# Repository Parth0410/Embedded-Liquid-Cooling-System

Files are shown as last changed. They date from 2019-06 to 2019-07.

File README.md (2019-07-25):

# Embedded-Liquid-Cooling-System
To maintain the Temperature of the water in the bottle.

About this Project:-

The Peltier Tile is the module which has two sides, one becomes cold and other heats up on applying the certain voltage. The main Objective of the project is to make a Liquid Cooler using a Peltier Tile. In this, the base is created which has the Microcontroller, Cooling Fan, and the Temperature sensors which continuously detects and display the temperature of the water as well as of the base in the display.  
As the temp. of water reaches the threshold level i.e., 15 ºC, the Fan and Peltier Tile stops working, and as the temp. again reaches above the threshold i.e., 25 ºC, both again starts working. This will help the battery to work for long duration and resulting the Water remains Cool.

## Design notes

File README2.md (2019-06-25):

Here for this project I designed my own PCB for microcontroller board as well as for the Boost circuit.
The purpose of designing my own PCB is to consider the size of PCB which should not be bigger than the base of the water bottle besause the development board are too big for this.

So, the details like block diagram, all data sheets required, circuit diagram, component list with values and their component code and the other required things are attached in this.

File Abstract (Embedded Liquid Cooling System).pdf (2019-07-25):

# Liquid Cooling Using Peltier Tile

## Abstract:

Our project is based on the Thermoelectric Effect. The Thermoelectric Effect is the direct conversion of temperature differences to electric voltage and vice versa via a thermocouple. A thermoelectric device creates voltage when there is a different temperature on each side. Conversely, when a voltage is applied to it, heat is transferred from one side to the other, creating a temperature difference. The term "Thermoelectric Effect" encompasses three separately identified effects which are: Seebeck Effect, Peltier Effect and Thomson Effect. The detailed description of all these effects you can see by clicking here. (https://en.wikipedia.org/wiki/Thermoelectric_effect)

So, for this project we are using a Peltier Module which works on the principle of Peltier Effect. The Peltier effect is the presence of heating or cooling at an electrified junction of two different conductors when a current is made to flow through a junction between two conductors, A and B, heat may be generated or removed at the junction.

For our project, we designed our own AVR Controller Board in Eagle CAD and it has the minimal peripherals we need because we have size and shape constraints.

The main Objective of the project is to make a Liquid Cooler using a Peltier Tile. In this, the base is created which has the Microcontroller board (Self-designed), Cooling Fan, and the Temperature sensors which continuously detects and display the temperature of the water in the LCD.

As the temp. of water reaches the threshold level i.e., 15 ºC, the Fan and Peltier Tile stops working, and as the temp. again reaches above the threshold i.e., 25 ºC, both again starts working. This will help the battery to work for long duration and resulting the Water remains Cool.

Project Members: | Project Guide:
1. Parth Rastogi (190250330050) | 1. Mr. Ninad
2. Piyush Sharma (190250330052) | C-DAC Hyderabad

### 3. Paras Srivastava (190250330049) 4. Pawar Nikesh Shivajirao (190250330051)

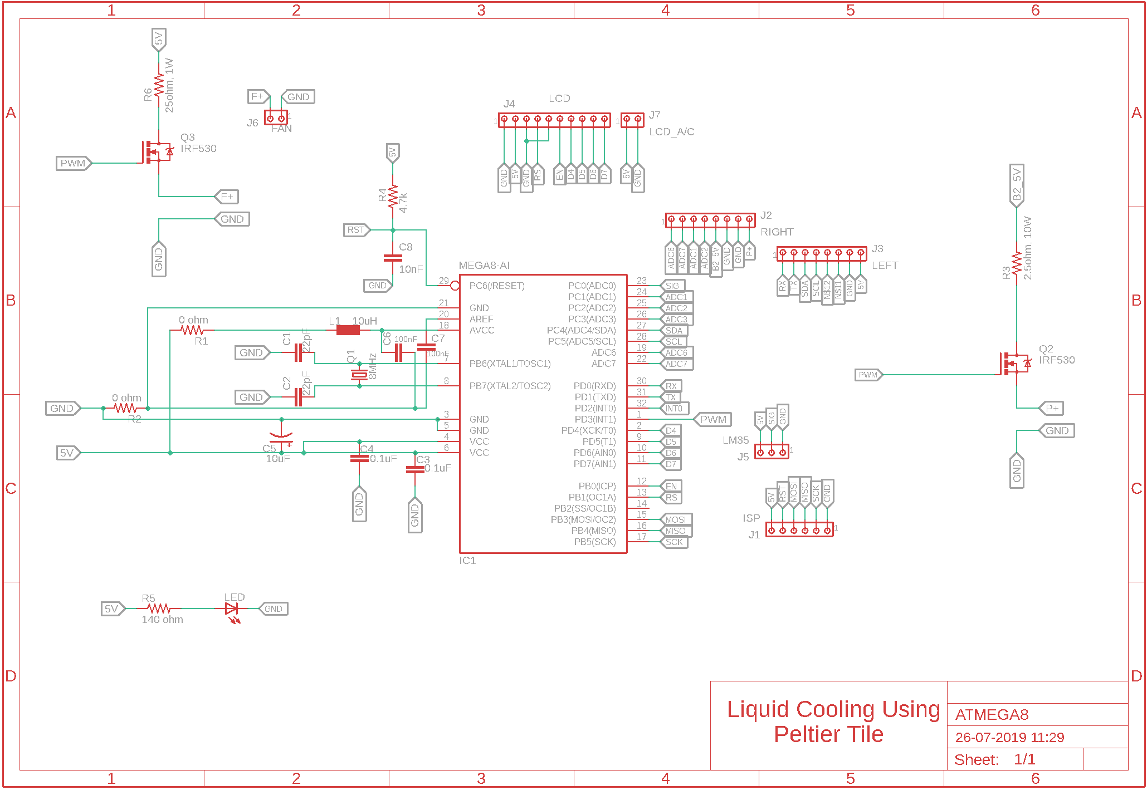
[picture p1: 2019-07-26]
Eagle Schematics Images/Final uC Board Schematic.png

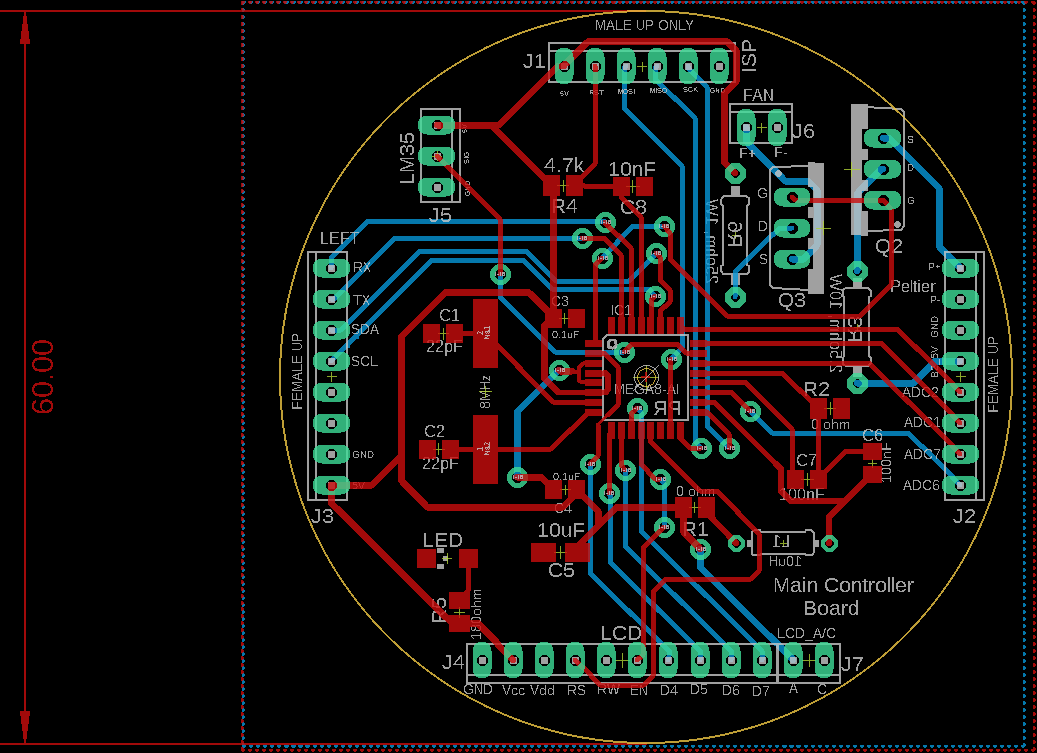
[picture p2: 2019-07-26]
Eagle Schematics Images/Final uC Board Layout.png

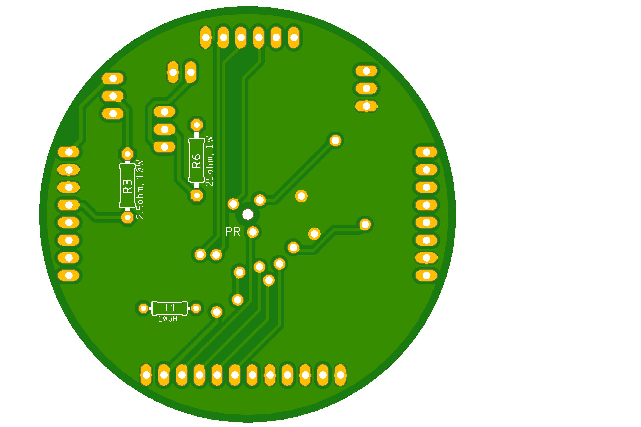
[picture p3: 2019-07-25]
Controller Board PCB Images/Final ATMEGA8 PCB_Bottom.png

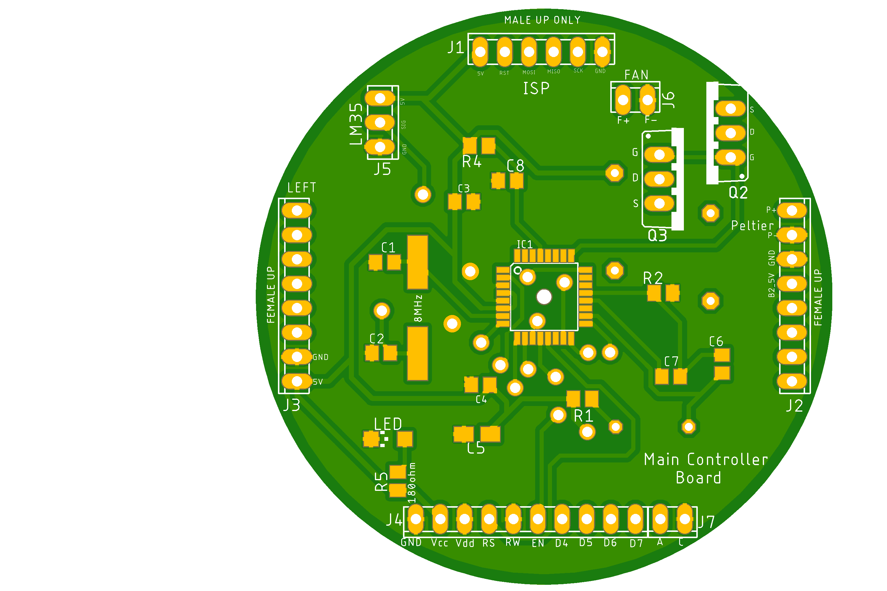
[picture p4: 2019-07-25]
Controller Board PCB Images/Final ATMEGA8 PCB_TOP.png

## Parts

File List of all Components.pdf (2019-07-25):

## (Updated List) Components List of Controller Board

Sr. No. | Component Name | Value | Quantity
1. | Atmega8 uC | 5V, 8MHz | 1
2. | Crystal (CMX-7X-DU) | 8MHz | 1
3. | Capacitor (C0805) | 100nF, 0.1uF (Ceramic) | 2, 2
4. | Capacitor (C0805) | 10nF, 22pF | 1, 2
5. Tantalum Capacitor | (A/3216-18R) | 10uF | 1
6. | Resistor (M0805) | 0 Ohm, 10K | 2, 1
7. | Resistor (M0805) | 4.7K ohm | 1
8. 8. | Resistor (M0805) | 140 ohms | 1
9. Inductor (MS42) | (PTH) | 10uH | 1
10. | Diode (1N4148) | N/A | 1
11. | LED (LED0805) | RED | 1
12. N-Channel Mosfet | (IRFZ44N) | TO202 | 2
13. | Power Resistor | 2.5ohm, 10Watt | 1
14. | Power Resistor | 25ohm, 1Watt | 1
15. Jumper 1-ISP | (10X06MTA) | 6 PINS | 1
16. Jumper 2-3- | RIGHT/LEFT (10X08MTA) | 8 PINS | 2
17. Jumper 4- LCD | (10X10MTA) | 12 PINS | 1
18. Jumper 5- LM35 | (10X03MTA) | 3 PINS | 1
19. Jumper 6- FAN | (10X02MTA) | 2 PINS | 1

## List of Peripherals Connected to Main Board

Sr. No. | Name | Model No. | Value | Quantity
1 | LM35 (Waterproof) | DS18B20 | 3V – 5.5V | 1
2 | LCD (16 X 2) | 16 x 2 | 3.3V – 5V | 1
3 | DC FAN | N/A | 5V | 1
4 | Li-ion Battery | N/A | 3.7V, 2000mAh | 2
5 | HEAT SINK | CentIot 40mm | N/A | 2
6 | Charger Module | TP4056 1A Li-ion | N/A | 1
7 | Boost Module | XL6009 | N/A | 2

NOTE:
* All the Components are SMD components except IRFZ44N Mosfets, Power Resistors and an Inductor.

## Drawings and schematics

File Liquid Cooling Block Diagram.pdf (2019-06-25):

### Atmega8

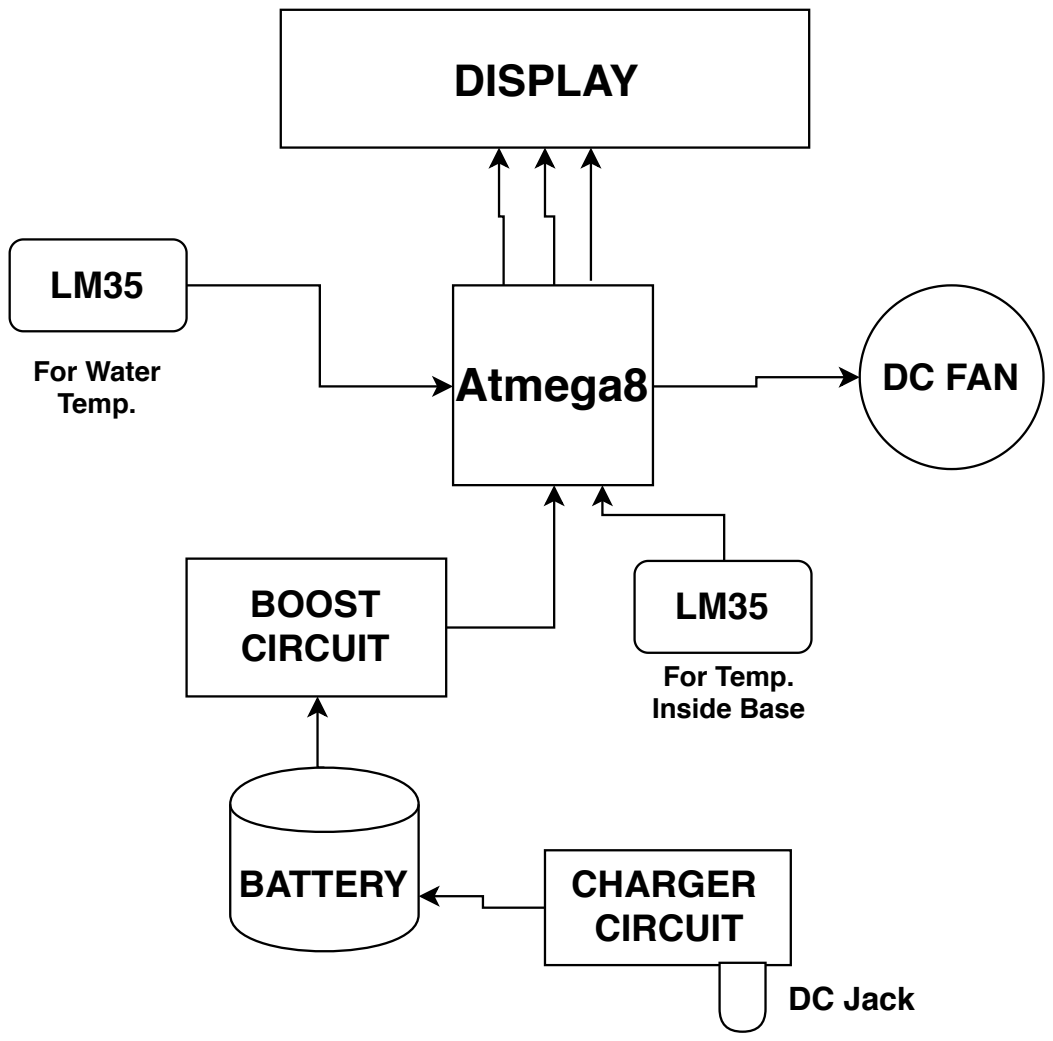
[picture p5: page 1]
DISPLAY; DC FAN; BATTERY; CHARGER; CIRCUIT; For Water Temp.; For Temp. Inside Base; DC Jack; BOOST CIRCUIT

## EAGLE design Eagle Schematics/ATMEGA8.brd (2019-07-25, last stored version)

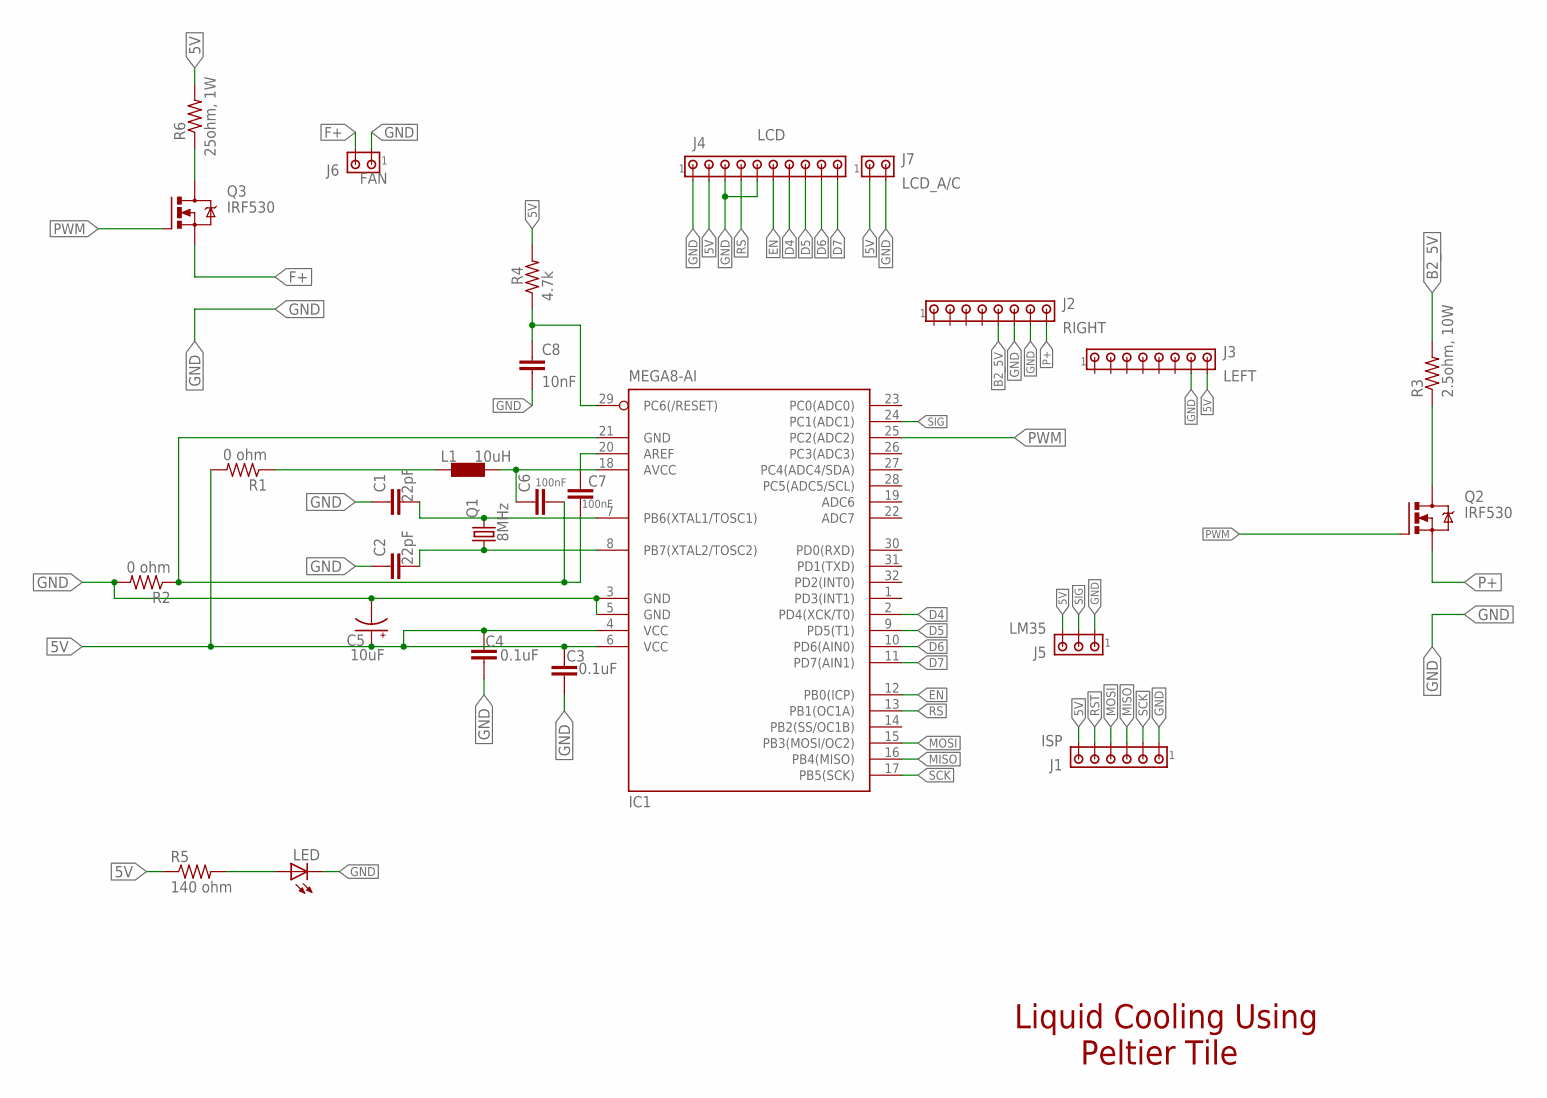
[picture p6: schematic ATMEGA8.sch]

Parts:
C1, C2: 22pF; C0805
C3, C4: 0.1uF; C0805
C5: 10uF; A/3216-18R
C6, C7: 100nF; C0805
C8: 10nF; C0805
IC1: MEGA8-AI; TQFP32-08
J1: ISP; 10X06MTA
J2: RIGHT; 10X08MTA
J3: LEFT; 10X08MTA
J4: LCD; 10X10MTA
J5: LM35; 10X03MTA
J6: FAN; 10X02MTA
J7: LCD_A/C; 10X02MTA
L1: 10uH; 0204/7
LED: RED; CHIPLED_1206
Q1: 8MHz; CSM-7X-DU
Q2, Q3: IRF530; TO220BV
R1, R2: 0 ohm; M0805
R3: 2.5ohm, 10W; 0207/9
R4: 4.7k; M0805
R5: 140 ohm; M0805
R6: 25ohm, 1W; 0207/10

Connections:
5V: C3.1, C4.1, C5.+, IC1.4 (VCC), IC1.6 (VCC), J1.6, J3.8, J4.2, J5.3, J7.1, R1.2, R4.2, R5.1, R6.2
B2_5V: J2.5, R3.2
D4: IC1.2 (PD4(XCK/T0)), J4.7
D5: IC1.9 (PD5(T1)), J4.8
D6: IC1.10 (PD6(AIN0)), J4.9
D7: IC1.11 (PD7(AIN1)), J4.10
EN: IC1.12 (PB0(ICP)), J4.6
F+: J6.2, Q3.S
GND: C1.1, C2.1, C3.2, C4.2, C5.-, C8.2, IC1.3 (GND), IC1.5 (GND), J1.1, J2.6, J2.7, J3.7, J4.1, J4.3, J4.5, J5.1, J6.1, J7.2, LED.C, R2.2
MISO: IC1.16 (PB4(MISO)), J1.3
MOSI: IC1.15 (PB3(MOSI/OC2)), J1.4
unnamed: C1.2, IC1.7 (PB6(XTAL1/TOSC1)), Q1.2
unnamed: C2.2, IC1.8 (PB7(XTAL2/TOSC2)), Q1.1
unnamed: C6.1, IC1.18 (AVCC), L1.2
unnamed: Q2.D, R3.1
unnamed: L1.1, R1.1
unnamed: C6.2, C7.2, IC1.21 (GND), R2.1
unnamed: C7.1, IC1.20 (AREF)
unnamed: C8.1, IC1.29 (PC6(/RESET)), R4.1
unnamed: LED.A, R5.2
unnamed: Q3.D, R6.1
P+: J2.8, Q2.S
PWM: IC1.25 (PC2(ADC2)), Q2.G, Q3.G
RS: IC1.13 (PB1(OC1A)), J4.4
RST: J1.5
SCK: IC1.17 (PB5(SCK)), J1.2
SIG: IC1.24 (PC1(ADC1)), J5.2

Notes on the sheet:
Liquid Cooling Using Peltier Tile

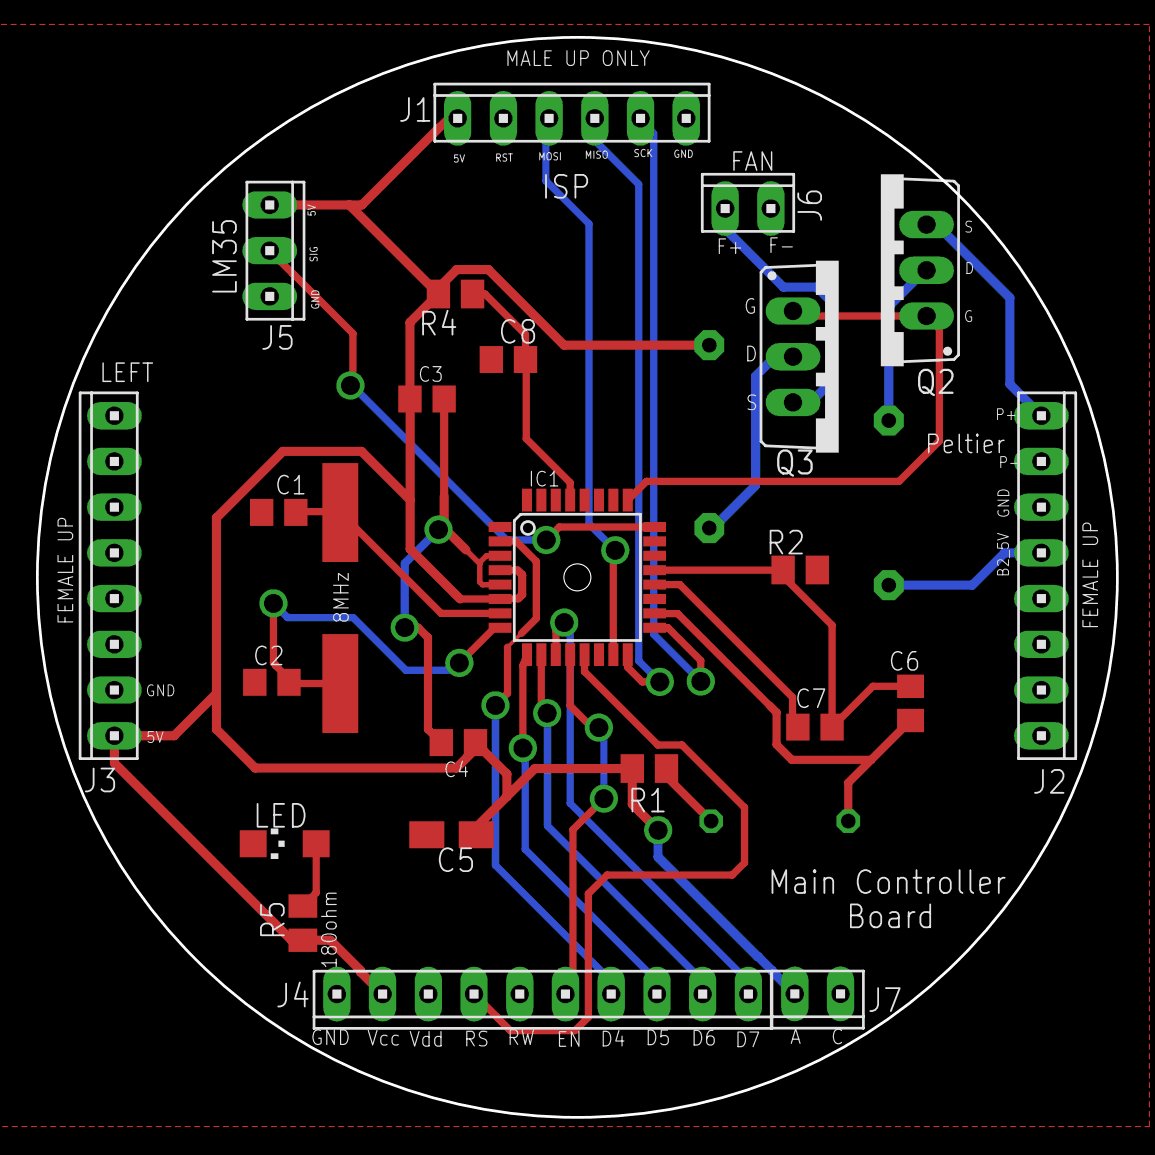
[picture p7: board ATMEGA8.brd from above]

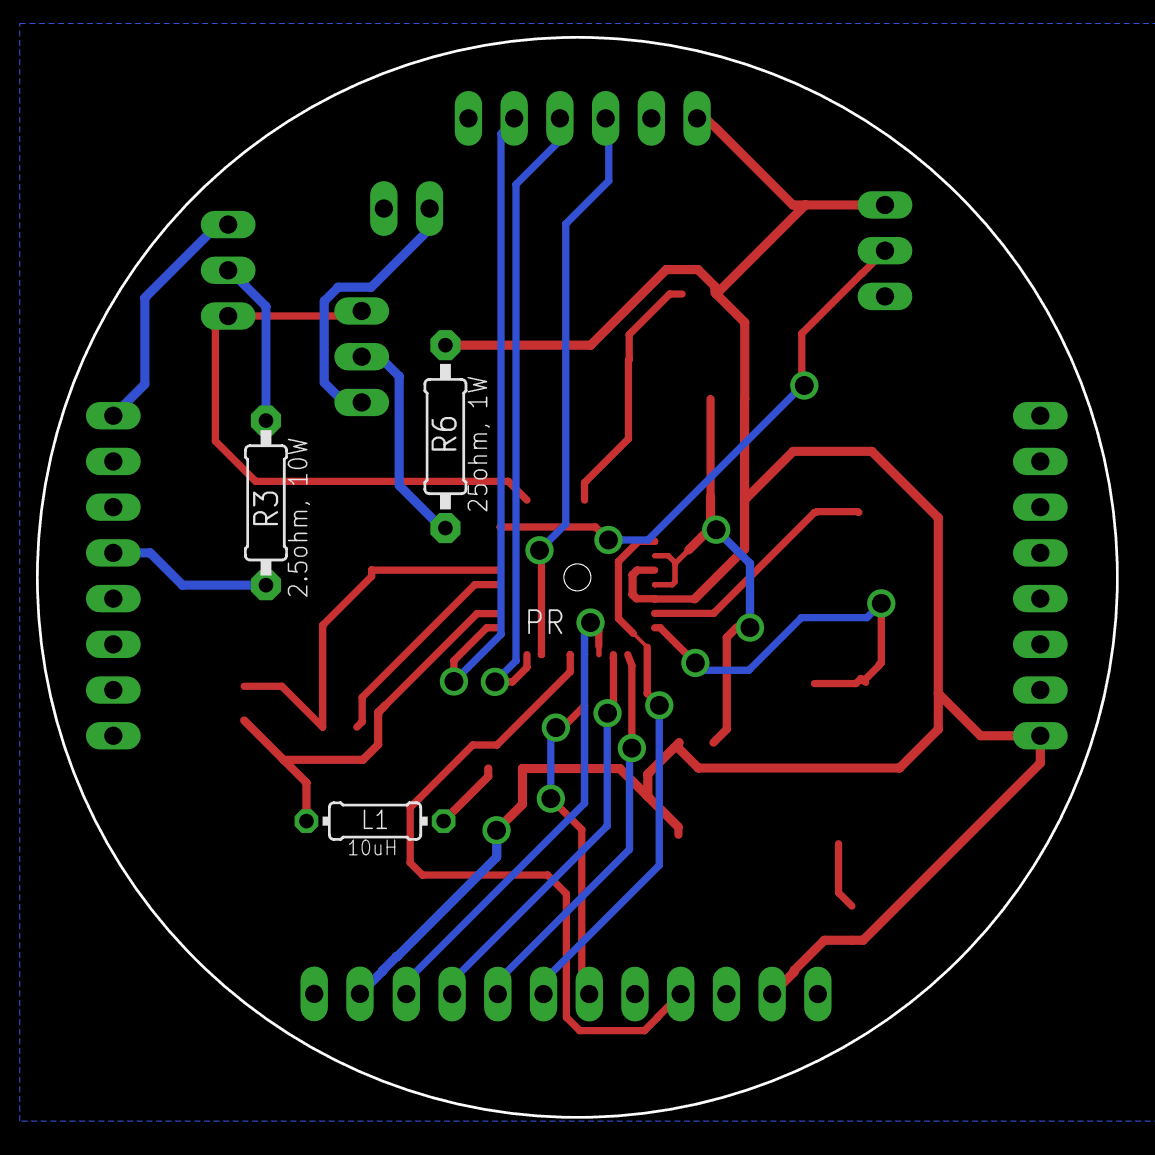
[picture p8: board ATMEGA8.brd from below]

Board: 2 copper layers, 60.0 x 60.0 mm, 27 parts (3 on the bottom side), 26 nets.

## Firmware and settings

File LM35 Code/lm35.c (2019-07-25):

#include <avr/io.h>
#include <util/delay.h>
#include <string.h>
#include <stdio.h>

#include "LCD_16x2_header.h"

#define degree_sysmbol 0xdf

void LCD_Command (char cmd)							/* LCD command write function */
{
	LCD_Data_Port = cmd & 0xF0;							/* Write command data to LCD data port */
	LCD_Command_Port &= ~((1<<RS)|(1<<RW));			/* Make RS LOW (command reg.), RW LOW (Write) */
	LCD_Command_Port |= (1<<EN);					/* High to Low transition on EN (Enable) */
	_delay_ms(5);
	LCD_Command_Port &= ~(1<<EN);
	_delay_ms(150);
	LCD_Data_Port = cmd <<4;
	LCD_Command_Port |= (1<<EN);
        _delay_ms(5);
	LCD_Command_Port &= ~(1<<EN);
	_delay_ms(150);									/* Wait little bit */
}

void LCD_Char (char char_data)						/* LCD data write function */
{
	LCD_Data_Port = char_data & 0xF0;						/* Write data to LCD data port */
	LCD_Command_Port &= ~(1<<RW);					/* Make RW LOW (Write) */
	LCD_Command_Port |= (1<<EN)|(1<<RS);
	_delay_ms(5);                                                  /* Make RS HIGH (data reg.) and High to Low transition on EN (Enable) */
	LCD_Command_Port &= ~(1<<EN); 
        _delay_ms(150);
	LCD_Command_Port &= ~(1<<EN);
        LCD_Data_Port = char_data << 4;
        LCD_Command_Port |= (1<<EN);
        _delay_ms(5);
        LCD_Command_Port &= ~(1<<EN);
	_delay_ms(150);									/* Wait little bit */
}

void LCD_Init (void)								/* LCD Initialize function */
{
	LCD_Command_Dir = 0xFF;     // |= (1<<RS)|(1<<RW)|(1<<EN);		/* Make LCD command port direction as o/p */
	LCD_Data_Dir = 0xFF;							/* Make LCD data port direction as o/p */
	
	_delay_ms(150);	
	LCD_Command (0x0E);		                        /* LCD power up time to get things ready, it should always >15ms */
	LCD_Command (0x33);								/* Initialize 16X2 LCD in 4 bit mode */
	LCD_Command (0x32);								
	LCD_Command (0x28);								/* Auto Increment cursor */
	LCD_Command (0x01);					                       /* Clear LCD command */
	 LCD_Command (0x06); 								/**/
	 LCD_Command (0x80);								/**/
	  LCD_Command (0x0C);								/*Display ON Cursor OFF*/    
   
   }

void LCD_String (char *str)							/* Send string to LCD function */
{
	int i;
	for(i=0;str[i]!=0;i++)							/* Send each char of string till the NULL */
	{
		LCD_Char (str[i]);							/* Call LCD data write */
	}
}

void LCD_String_xy (char row, char pos, char *str)	/* Send string to LCD function */
{
	if (row == 1)
		LCD_Command((pos & 0x0F)|0x80);				/* Command of first row and required position<16 */
	else if (row == 2)
		LCD_Command((pos & 0x0F)|0xC0);				/* Command of Second row and required position<16 */
	LCD_String(str);								/* Call LCD string function */
}

void LCD_Clear()
{
	LCD_Command(0x01);								/* clear display */
}

void ADC_Init()
{										
	DEVICE_Command_Dir |= (1<<PC2);					 /* Make ADC port as Output for Peltier and FAN */
	ADCSRA = 0x87;								/* Enable ADC, with freq/128  */
	ADMUX = 0x40;								/* Vref: Avcc, ADC channel: 0 */
}

int ADC_Read(char channel)							
{
	ADMUX = 0x40 | (channel & 0x07);				/* set input channel to read */
	ADCSRA |= (1<<ADSC);							/* Start ADC conversion */
	while (!(ADCSRA & (1<<ADIF)));					/* Wait until end of conversion by polling ADC interrupt flag */
	ADCSRA |= (1<<ADIF);							/* Clear interrupt flag */
	_delay_ms(1);									/* Wait a little bit */
	return ADCW;									/* Return ADC word */
}


int main()
{
	char Water_Temp[10];
	float celsius;
	char device[10]= {'\0'};
	LCD_Init();                 /* initialize 16x2 LCD*/
	ADC_Init();                 /* initialize ADC*/
	int prev =0;
	while(1)
	{
		LCD_String_xy(1,0,"Water Temperature");
	   
		celsius = (ADC_Read(1)*4.88);
		celsius = (celsius/10.00);
		sprintf(Water_Temp,"%d%cC\t            ", (int)celsius, degree_sysmbol);               /* convert integer value to ASCII string */
		LCD_String_xy(2,0,Water_Temp);                /* send string data for printing */
		
	  
		 
	       if( celsius >= 25)
	       {
		  strcpy(device,"Device=ON ");
		  DEVICE_Command_PORT &= ~(1<<PC2);
		  //DEVICE_Command_PORT |= (1<<PC2);
		  LCD_String_xy(2,6,device); 
		  _delay_ms(1000);
		   prev = 1;
		  
	       }
	       else if(celsius <15)
	       {
		  DEVICE_Command_PORT |= (1<<PC2);
		  //DEVICE_Command_PORT &= ~(1<<PC2);
		 strcpy(device,"Device=OFF");
		  LCD_String_xy(2,6,device); 
		  _delay_ms(1000);
		  prev = 0;
		   
	       }
	       else if(prev == 1)
	       {
		   strcpy(device,"Device=ON ");
		  DEVICE_Command_PORT &= ~(1<<PC2);
		  //DEVICE_Command_PORT |= (1<<PC2);
		  LCD_String_xy(2,6,device); 
		  _delay_ms(1000);  
	       }
	      
	   
		memset(Water_Temp,0,10);
	}
	return 0;
}

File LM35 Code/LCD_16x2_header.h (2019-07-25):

#ifndef LCD_16x2_header					/* Define library H file if not defined */
#define LCD_16x2_header


#define LCD_Data_Dir DDRD				/* Define LCD data port direction */
#define LCD_Command_Dir DDRB			/* Define LCD command port direction register */
#define LCD_Data_Port PORTD				/* Define LCD data port */
#define LCD_Command_Port PORTB			/* Define LCD command port */
#define DEVICE_Command_Dir DDRC                                              /*Direction for the Peltier & FAN*/
#define DEVICE_Command_PORT PORTC		/*PORT for the Peltier & FAN*/
#define EN PB0					/* Define Enable signal pin */
#define RW PB3	       /*NO NEED, GROUNDED IN THE CIRCUIT*/		/* Define Read/Write signal pin */
#define RS PB1							/* Define Register Select (data reg./command reg.) signal pin */

void LCD_Command (char);				/* LCD command write function */
void LCD_Char (char);					/* LCD data write function */
void LCD_Init (void);					/* LCD Initialize function */
void LCD_String (char*);				/* Send string to LCD function */
void LCD_String_xy (char,char,char*);	/* Send row, position and string to LCD function */
void LCD_Clear();						/* Clear LCD*/

#endif

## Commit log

2019-06-25 Eagle Library for ADP1613 IC
    Library for Boost Circuit IC
2019-07-25 Add files via upload
    Code for controlling the Peltier and Fan with a threshold.
2019-07-25 Images
    For your reference how the Controller Board looks like.
2019-07-25 Eagle Schematics for Controller Board
    It contains the Eagle Schematic file and Layout file of the Controller Board.
    [ATMEGA8.brd, ATMEGA8.sch]
2019-07-25 Components and Peripherals list
    List of all components and other Peripherals which are needed for the Board.
2019-07-26 Circuit Diagram drawn on Eagle
